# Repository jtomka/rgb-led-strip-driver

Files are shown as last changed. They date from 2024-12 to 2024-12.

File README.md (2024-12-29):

# 12V RGB LED Strip Driver

12V driven by power MOSFETs, controlled by three 3V3-5V GPIOs.

To be powered by a 12VDC/5A power supply, enough to drive 300 diodes,
typically 5M in length. Includes a 5V voltage regulator for the MCU
board.

At 75MM x 25MM, the board comes with enough space for a vertically
placed Waveshare ESP32-S3-Zero, but can be controlled via three GPIOs
from any source.

#### Sources of Information:

* https://learn.adafruit.com/rgb-led-strips/usage
* https://kno.wled.ge/basics/compatible-led-strips/#non-addressable-led-strips

#### Using With Waveshare ESP-S3-Zero and WLED

* https://github.com/jtomka/wled-esp32-s3-zero

#### Images

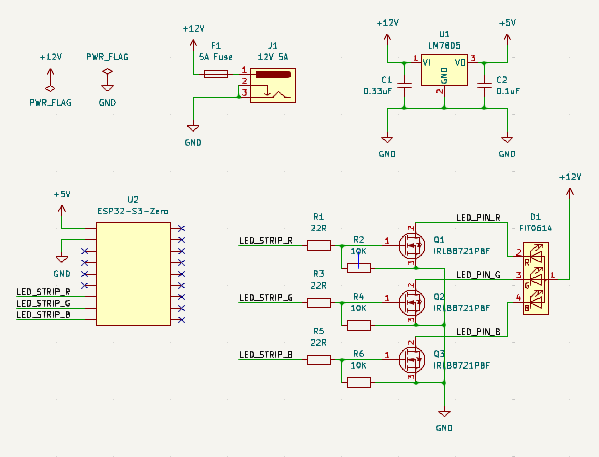
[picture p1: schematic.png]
Schematic


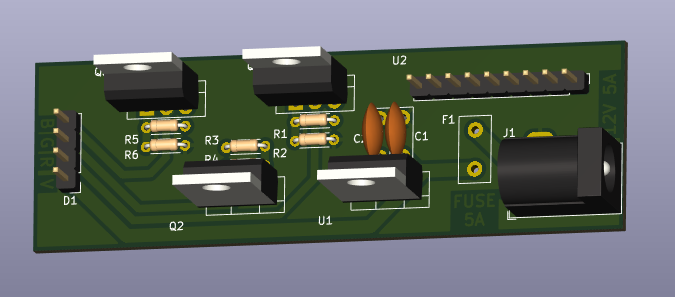
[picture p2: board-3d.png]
Board 3D


WLED Setup

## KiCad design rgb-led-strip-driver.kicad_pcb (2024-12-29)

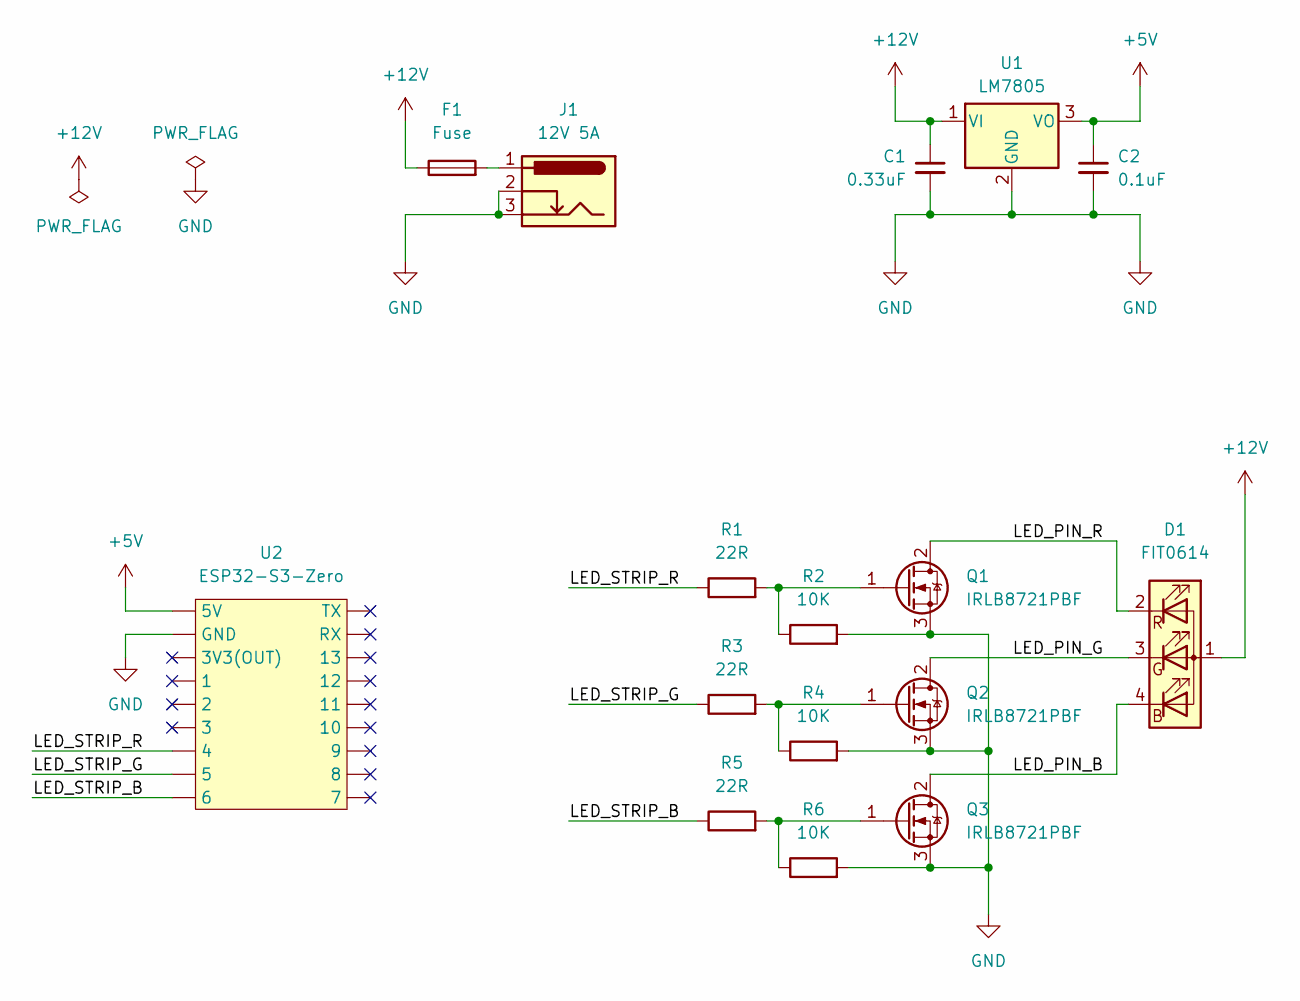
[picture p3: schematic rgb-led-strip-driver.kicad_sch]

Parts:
C1: 0.33uF; C_Disc_D7.5mm_W2.5mm_P5.00mm
C2: 0.1uF; C_Disc_D7.5mm_W2.5mm_P5.00mm
D1: FIT0614; PinHeader_1x04_P2.54mm_Vertical
F1: Fuse; FuseHolder_Blade_ATO_Littelfuse_FLR_178.6165
J1: 12V 5A; BarrelJack_Horizontal
Q1, Q2, Q3: IRLB8721PBF; TO-220-3_Vertical
R1, R3, R5: 22R; R_Axial_DIN0204_L3.6mm_D1.6mm_P5.08mm_Horizontal
R2, R4, R6: 10K; R_Axial_DIN0204_L3.6mm_D1.6mm_P5.08mm_Horizontal
U1: LM7805; TO-220-3_Vertical
U2: ESP32-S3-Zero; PinHeader_1x09_P2.54mm_Vertical

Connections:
+5V: C2.1, U1.3 (VO), U2.1 (5V)
+12V: C1.1, D1.1 (A), F1.1, U1.1 (VI)
/LED_PIN_B: D1.4 (BK), Q3.2 (D)
/LED_PIN_G: D1.3 (GK), Q2.2 (D)
/LED_PIN_R: D1.2 (RK), Q1.2 (D)
/LED_STRIP_B: R5.1, U2.9 (6)
/LED_STRIP_G: R3.1, U2.8 (5)
/LED_STRIP_R: R1.1, U2.7 (4)
GND: C1.2, C2.2, J1.2, J1.3, Q1.3 (S), Q2.3 (S), Q3.3 (S), R2.2, R4.2, R6.2, U1.2 (GND), U2.2 (GND)
unnamed: F1.2, J1.1
unnamed: Q1.1 (G), R1.2, R2.1
unnamed: Q2.1 (G), R3.2, R4.1
unnamed: Q3.1 (G), R5.2, R6.1

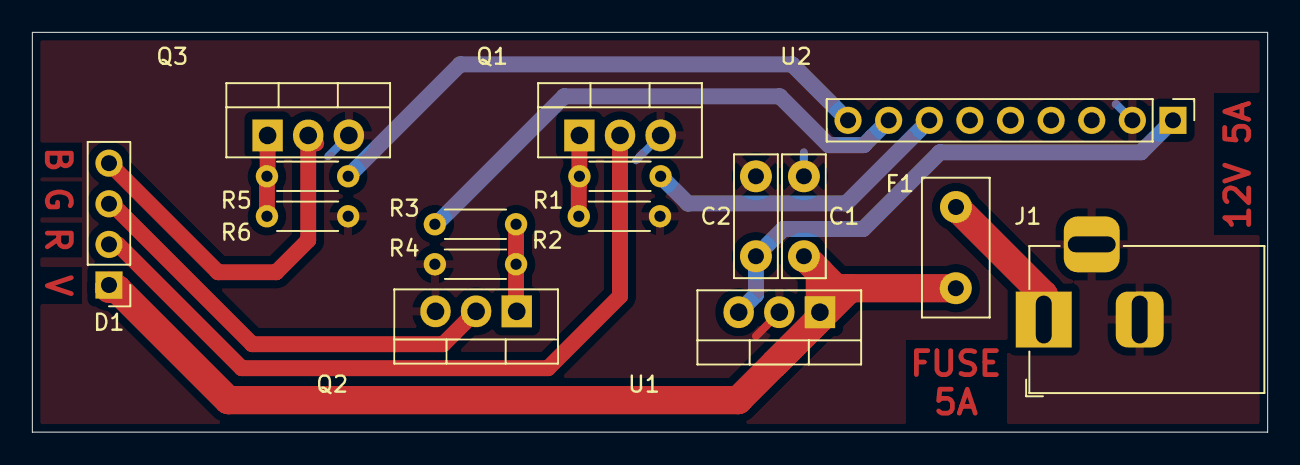
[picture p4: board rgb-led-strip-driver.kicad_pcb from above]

Board: 2 copper layers, 77.2 x 25.0 mm, 16 parts (0 on the bottom side), 13 nets.
